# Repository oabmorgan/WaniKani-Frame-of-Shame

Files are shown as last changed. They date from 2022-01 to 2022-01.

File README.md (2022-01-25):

# WaniKani Frame of Shame
 Stop ignoring those reviews you've got stacking up! The WaniKani Frame of Shame grabs all your waiting reviews and displays them so you can't ignore them anymore. It works by lighting up an LED for each review thats waiting, colored by SRS level. When you complete the review, the light turns off again. Keep reviewing to keep the lights off!
 
front

Easy to make, no soldering required!
**Estimated cost: ~$20**

## Materials
 - 16x16 WS2812B LED Matrix 
   - https://www.aliexpress.com/item/4000544584524.html
 - V2 Nodemcu ESP8266
   - https://www.aliexpress.com/item/32665100123.html
 - 3x Male to Female Dupont Jumper Cables
   - https://www.aliexpress.com/item/4000848184096.html
 - Frame that fits at least 160 x 160mm
 - Micro USB Cable

## Instructions
* Make a hole in the backing board of the frame for the input wires to go through. You can remove the output port and the extra voltage wires.

wiring guide
* Fit the LED matrix into the frame. I used double sided tape make it lie flat on backing board. 
* Download and open [WaniKani.ino](https://github.com/oabmorgan/WaniKani-Frame-of-Shame/blob/main/WaniKani/WaniKani.ino) (you need the [Arduino IDE installed and set up for the ESP8266 (2.7.4)](https://arduino-esp8266.readthedocs.io/en/latest/installing.html) if it's not already) and make the following changes.
  * ` const char* ssid = "SSID"; ` Fill in your WiFi SSID
  * ` const char* password = "PASSWORD"; ` Fill in your WiFi Password
  * `const char* apiKey = "WK-API-KEY";` Fill in your [WaniKani API Key](https://www.wanikani.com/settings/personal_access_tokens)
  * `const char* timezone = "TIMEZONECODE";` Fill in your [timezone code](https://github.com/nayarsystems/posix_tz_db/blob/master/zones.csv)
* You also need to make sure you have the libraries listed at the top installed. [How?](https://www.arduino.cc/en/guide/libraries#toc3)
* Upload the sketch and then unplug the usb cable.
* Use Dupont jumper cables to attach the LED matrix to the board
  * ` RED -> VIN`
  * ` GREEN -> D4`
  * ` WHITE -> GND`
* Reattach the usb cable and you're done!

* Optionally, i've included a [case to 3D Print](https://github.com/oabmorgan/WaniKani-Frame-of-Shame/tree/main/STLs).
back

## Required Libraries
- ArduinoJson
- FastLED

## Troubleshooting
Make sure the `LED_PIN` is set correctly.
Try using a different pin order by swapping beween these lines:

`#define FASTLED_ESP8266_RAW_PIN_ORDER`

`//#define FASTLED_ESP8266_NODEMCU_PIN_ORDER`

`//#define FASTLED_ESP8266_D1_PIN_ORDER`

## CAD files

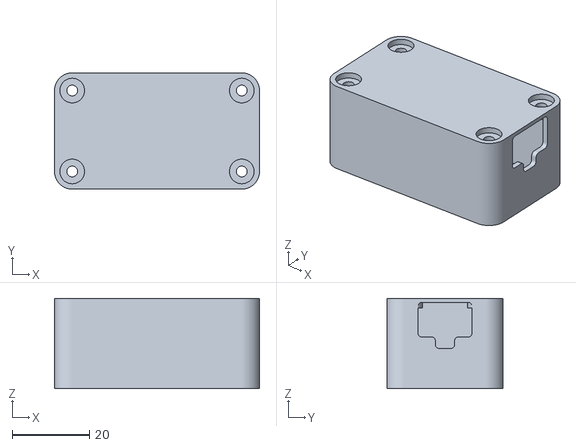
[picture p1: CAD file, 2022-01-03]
STLs/ESP8266_Top.stl
53.2 x 30.2 x 23.4

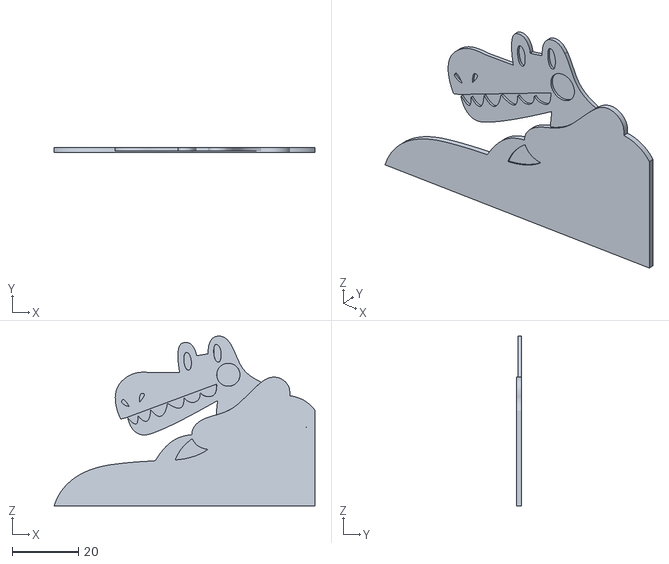
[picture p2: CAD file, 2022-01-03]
STLs/Crabigator.stl
78.9 x 1.40 x 51.4

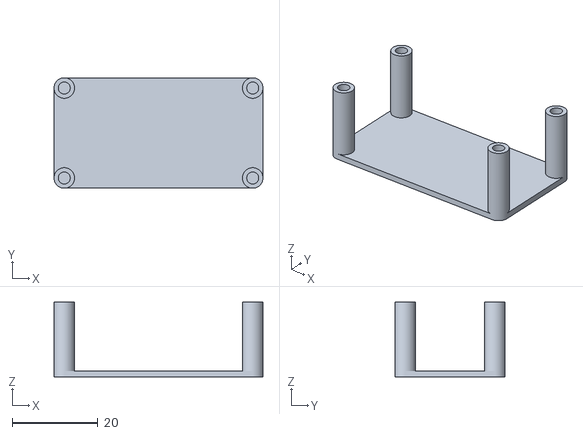
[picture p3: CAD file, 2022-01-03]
STLs/ESP8266_Base.stl
48.8 x 25.8 x 17.4

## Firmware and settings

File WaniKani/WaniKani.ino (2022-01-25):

#define FASTLED_ESP8266_RAW_PIN_ORDER
#include <ESP8266WiFi.h>
#include <ESP8266HTTPClient.h>
#include <WiFiClient.h>
#include <ArduinoJson.h>
#include <FastLED.h>
#include <time.h>

/*  Basic Settings  */

const char* ssid = "SSID";
const char* password = "PASSWORD";
const char* apiKey = "WK-API-KEY"; //https://www.wanikani.com/settings/personal_access_tokens
const char* timezone = "TIMEZONECODE"; //https://github.com/nayarsystems/posix_tz_db/blob/master/zones.csv

//Example time zones
//const char* timezone = "JST-9";                            // Japan
//const char* timezone = "GMT0BST,M3.5.0/01,M10.5.0/02";     // UK
//const char* timezone = "MET-2METDST,M3.5.0/01,M10.5.0/02"; // Most of Europe
//const char* timezone = "CET-1CEST,M3.5.0,M10.5.0/3";       // Central Europe
//const char* timezone = "EST-2METDST,M3.5.0/01,M10.5.0/02"; // Most of Europe
//const char* timezone = "EST5EDT,M3.2.0,M11.1.0";           // EST USA
//const char* timezone = "CST6CDT,M3.2.0,M11.1.0";           // CST USA
//const char* timezone = "MST7MDT,M4.1.0,M10.5.0";           // MST USA
//const char* timezone = "NZST-12NZDT,M9.5.0,M4.1.0/3";      // Auckland
//const char* timezone = "EET-2EEST,M3.5.5/0,M10.5.5/0";     // Asia
//const char* timezone = "ACST-9:30ACDT,M10.1.0,M4.1.0/3":   // Australia


/*  Advanced Settings  */

//show lessons too?
bool showLessons = true;

//How frequently to update, in minutes
unsigned long timerDelay = 15;

//What colors to use for the color gradient. https://uigradients.com/#Timber can give you some quick options.
#define colorA CRGB(0xff1493)
#define colorB CRGB(0x00bfff)
#define colorLesson CRGB(0xffffff)

//Max power to draw, controls the brightness of the LEDs. If you're powering this with USB, keep this under 450.
const uint8_t maxPower = 400;

/*  End of Settings */


unsigned long scaledTime;
#define LED_PIN  14

#define COLOR_ORDER GRB
#define CHIPSET     WS2812B

//hostnames
const char* serverName = "https://api.wanikani.com/v2/assignments?";
const char* timeHost      = "http://api.timezonedb.com/v2/get-time-zone?key=******&format=xml&fields=formatted&by=zone&zone=Asia/Tokyo";

// Params for width and height
const uint8_t kMatrixWidth = 16;
const uint8_t kMatrixHeight = 16;

#define NUM_LEDS (kMatrixWidth * kMatrixHeight)
CRGB leds_plus_safety_pixel[ NUM_LEDS + 1];
CRGB* const leds( leds_plus_safety_pixel + 1);

int pos = 0;

void setup() {
  pinMode(LED_BUILTIN, OUTPUT);
  FastLED.addLeds<CHIPSET, LED_PIN, COLOR_ORDER>(leds, NUM_LEDS).setCorrection(TypicalSMD5050);
  FastLED.setMaxPowerInVoltsAndMilliamps(5, maxPower); //max 500 for usb
  Serial.begin(115200);
  WiFi.begin(ssid, password);
  Serial.println("Connecting");
  while (WiFi.status() != WL_CONNECTED) {
    delay(100);
  }
  Serial.println(WiFi.localIP());
  configTime(0, 0, "pool.ntp.org", "time.nist.gov");
  setenv("TZ", timezone, 1);
  pos = 0;
}

int get_time() {
  time_t now;
  time(&now);
  char time_output[30];
  strftime(time_output, 30, "%H", localtime(&now));
  return String(time_output).toInt();
}

void setLED(int SRS) {
  if (pos < NUM_LEDS) {
    if (SRS == 0) {
      leds[pos] = colorLesson;
      FastLED.show();
      delay(10);
    }
    else if (SRS < 10) {
      leds[pos] = CRGB::White;
      FastLED.show();
      delay(10);
      leds[pos] = blend(colorA, colorB, 30 * SRS);
      delay(10);
    } else {
      leds[pos].fadeToBlackBy(192);
      delay(10);
    }
    pos ++;
    FastLED.show();
  }
}

void loop() {
  digitalWrite(LED_BUILTIN, LOW);
  Serial.println("Update Running");
  pos = 0;
  if (WiFi.status() == WL_CONNECTED) {
    WiFiClientSecure client;
    client.setInsecure();
    Serial.println("Connected");
    Serial.println("Updating time");
    int currentHour = get_time();
    Serial.println("Hour: " + (String)currentHour);
    switch (currentHour) {
      case 1:
      case 2:
      case 3:
      case 4:
      case 5:
      case 6:
        Serial.println("Low Power Mode");
        FastLED.setMaxPowerInVoltsAndMilliamps(5, maxPower * 0.5); //max 500 for usb
        scaledTime = timerDelay * 6;
        break;
      case 23:
      case 24:
      case 7:
      case 8:
      case 9:
        Serial.println("Med Power Mode");
        FastLED.setMaxPowerInVoltsAndMilliamps(5, maxPower * 0.75); //max 500 for usb
        scaledTime = timerDelay * 3;
        break;
        break;
      default:
        Serial.println("High Power Mode");
        FastLED.setMaxPowerInVoltsAndMilliamps(5, maxPower); //max 500 for usb
        scaledTime = timerDelay;
        break;
    }

    if (showLessons) {
      Serial.println("Lessons");
      HTTPClient http;
      http.useHTTP10(true);
      String urlString;
      urlString = serverName + (String)"immediately_available_for_lessons=true";
      http.begin(client, urlString);
      http.addHeader("Authorization", "Bearer " + (String)apiKey);
      http.GET();

      StaticJsonDocument<64> filter;
      filter["total_count"] = true;

      DynamicJsonDocument doc(2048);

      DeserializationError error = deserializeJson(doc, http.getStream(), DeserializationOption::Filter(filter));

      if (error) {
        Serial.print(F("deserializeJson() failed: "));
        Serial.println(error.f_str());
      }

      int total_count = doc["total_count"];
      Serial.println("Lessons: " + (String)total_count);

      for (int i = 0; i < doc["total_count"]; i++) {
        setLED(0);
      }
    }

    for (int srs = 0; srs < 9; srs++) {
      Serial.println("SRS: " + (String)srs);
      HTTPClient http;
      http.useHTTP10(true);
      String urlString;
      urlString = serverName + (String)"immediately_available_for_review=true&srs_stages=" + (String)srs;
      http.begin(client, urlString);
      http.addHeader("Authorization", "Bearer " + (String)apiKey);
      http.GET();

      StaticJsonDocument<64> filter;
      filter["total_count"] = true;

      DynamicJsonDocument doc(2048);

      DeserializationError error = deserializeJson(doc, http.getStream(), DeserializationOption::Filter(filter));

      if (error) {
        Serial.print(F("deserializeJson() failed: "));
        Serial.println(error.f_str());
      }

      int total_count = doc["total_count"];
      Serial.println("Reviews: " + (String)total_count);

      for (int i = 0; i < doc["total_count"]; i++) {
        setLED(srs);
      }
    }
  }
  Serial.println("You have " + (String)pos + " reviews + lessons");
  while (pos < NUM_LEDS) {
    setLED(10);
  }

  Serial.println("Going to sleep. See you in " + (String)scaledTime + " minutes." );
  digitalWrite(LED_BUILTIN, HIGH);
  wifi_set_sleep_type(LIGHT_SLEEP_T);
  delay(scaledTime * 60000);
  wifi_set_sleep_type(NONE_SLEEP_T);
}
